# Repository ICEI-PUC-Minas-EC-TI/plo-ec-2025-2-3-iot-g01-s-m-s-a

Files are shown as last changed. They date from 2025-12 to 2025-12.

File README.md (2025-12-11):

# Sistema de Monitoramento de Segurança de um Avião

Pontifícia Universidade Católica de Minas Gerais (PUC Minas) - Campus Lourdes

**Curso:** Engenharia de Computação

**Semestre:** Terceiro

**Disciplina:** Internet das Coisas I

## Integrantes

* Daniel Cássio Ornelas de Almeida
* Flávio Guto Teixeira Bezerra
* Gustavo Parreira Epólita
* Henrique Augusto Figueiredo Feydit Vieira
* Izabela Naves dos Santos

## Orientador

* Julio Cesar Dillinger Conway

## Resumo

Este projeto consiste no desenvolvimento de um protótipo de sistema de monitoramento de segurança interno para aeronaves. O sistema utiliza microcontroladores (ESP32/Arduino) integrados a sensores de pressão, temperatura e peso para detectar despressurização, incêndio e turbulência. Além do monitoramento, o projeto inclui atuadores para portas, luzes e exaustores de emergência, permitindo visualização e controle remoto via aplicativo móvel.

# Código (esp32)

<ol>
<li><a href="Codigo"> Arquivos</a></li>
<li><a href="Codigo/Código Fonte.cpp"> Código Fonte (.cpp)</a></li>
</ol>

# Aplicativo para Smartphone

<ol>
<li><a href="App"> Aplicativo </a></li>
</ol>

# Apresentação

<ol>
<li><a href="Apresentacao/README.md"> Vídeo do Funcionamento</a></li>
<li><a href="Apresentacao/README.md"> Fotos do Projeto</a></li>
</ol>

# Manual de Utilização

<ol>
<li><a href="Manual/manual de utilização.md"> Manual de Utilização</a></li>
</ol>

# Arquivos de modelagem 3D

<ol>
<li><a href="Arquivos 3d"> Arquivos de modelagem 3d</a></li>
</ol>

# Documentação

<ol>
<li><a href="Documentacao/01-Introducão.md"> Introdução</a></li>
<li><a href="Documentacao/02-Metodologias Ágeis.md"> Metodologias Ágeis</a></li>
<li><a href="Documentacao/03-Desenvolvimento.md"> Desenvolvimento </a></li>
<li><a href="Documentacao/04-Testes.md"> Testes </a></li>
<li><a href="Documentacao/05-Conclusão.md"> Conclusão </a></li>
<li><a href="Documentacao/06-Referências.md"> Referências </a></li>
</ol>

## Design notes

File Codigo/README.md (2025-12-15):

# Código-Fonte do Firmware (ESP32)

Este diretório contém o código-fonte C++ desenvolvido para o microcontrolador **ESP32**, responsável por gerenciar todo o sistema de segurança da aeronave. O projeto foi estruturado utilizando o **Visual Studio Code** com a extensão **PlatformIO**.

## Estrutura dos Arquivos

* **`Código Fonte.cpp`**: Arquivo principal contendo a lógica do sistema. Inclui:
    * `setup()`: Inicialização de sensores (I2C), conexão WiFi, configuração de pinos PWM/Servos e WebServer.
    * `loop()`: Gerenciamento de multitarefas (Timers não-bloqueantes), leitura de sensores, filtro complementar (IMU) e comunicação MQTT/WebSocket.
* **`index.html`**: Arquivo de interface (Frontend) hospedado na memória do ESP32 via LittleFS. Contém o código HTML/JavaScript responsável por renderizar o **Horizonte Artificial 3D** e conectar-se ao WebSocket.
* **`platformio.ini`**: Arquivo de configuração do ambiente de desenvolvimento. Define a placa (board), velocidade do monitor serial e as bibliotecas externas necessárias para compilação.

## Dependências e Bibliotecas

Para compilar este projeto, as seguintes bibliotecas são utilizadas (gerenciadas automaticamente pelo `platformio.ini`):

1.  **Sensores:**
    * `MPU6500_WE`: Leitura e calibração do Acelerômetro e Giroscópio.
    * `Adafruit_BMP280`: Leitura de Pressão Atmosférica e Temperatura.
2.  **Conectividade:**
    * `PubSubClient`: Protocolo MQTT para envio de telemetria e recebimento de comandos.
    * `ESPAsyncWebServer` & `AsyncTCP`: Servidor Web assíncrono para hospedar a interface local.
    * `WebSocketsServer`: Comunicação em tempo real para o Horizonte Artificial.
3.  **Atuadores:**
    * `ESP32Servo`: Controle preciso dos servomotores (Portas e Máscaras).

## Principais Funcionalidades Implementadas

### 1. Multitarefa
O código não utiliza `delay()` no loop principal. Foram implementados timers baseados em `millis()` para separar tarefas críticas:
* **100ms (Alta Prioridade):** Leitura do IMU, cálculo de vibração e atualização do WebSocket.
* **1000ms (Baixa Prioridade):** Leitura de Pressão/Temperatura (BMP280) e envio de telemetria pesada via MQTT.

### 2. Filtro Complementar (IMU)
Implementação matemática para fusão de sensores (Acelerômetro + Giroscópio) com fator `ALPHA = 0.96`, eliminando o ruído do acelerômetro e o *drift* do giroscópio para obter ângulos de *Pitch*, *Roll* e *Yaw* estáveis.

### 3. Interface Web (Horizonte Artificial 3D)
O sistema hospeda uma página HTML na memória flash do ESP32 (via sistema de arquivos **LittleFS**).
* **Representação 3D:** A página renderiza um modelo 3D da aeronave que se move em tempo real.
* **Comunicação:** Utiliza **WebSockets** (porta 81) para enviar pacotes JSON contendo os ângulos de Euler calculados pelo filtro. Isso permite que o avião na tela imite instantaneamente os movimentos físicos do protótipo (Digital Twin).

### 4. Modos de Simulação
Sistema de flags que permite simular emergências sem a necessidade de condições físicas reais, ativadas via MQTT ou Serial:
* 🔥 Incêndio (Luzes estroboscópicas + Sirene bitonal).
* 💨 Despressurização (Máscaras caem + Sirene contínua).
* ✈️ Turbulência (Alertas de vibração).

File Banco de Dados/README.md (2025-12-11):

# Apresentação da Solução
## Como rodar o projeto:

### 1. Configuração do Banco
O sistema utiliza o Google Cloud SQL. É necessário criar um banco chamado `IoT` e liberar o IP nas configurações de rede.

### 2. Configuração do Python
Instale as dependências:
pip install paho-mqtt mysql-connector-python

Edite o arquivo `main.py` com suas credenciais do banco e execute:
python main.py

## Código ultilizado:
import paho.mqtt.client as mqtt
import mysql.connector
import sys

# CONFIGURAÇÕES DO GOOGLE CLOUD SQL 
CLOUD_SQL_IP = '34.41.42.27'       
CLOUD_SQL_SENHA = 'SUA_SENHA_AQUI' 

# Configurações do Avião
TOPICO_ALVO = "aviao/sensor/temperaturabmp"
BROKER = "test.mosquitto.org"
PORTA = 1883

print(f"Tentando conectar ao Google Cloud SQL no IP: {CLOUD_SQL_IP}...")

try:
    con = mysql.connector.connect(
        host=CLOUD_SQL_IP,
        user='root',
        password=CLOUD_SQL_SENHA,
        database='IoT' 
    )
except mysql.connector.Error as err:
    print(f"ERRO DE CONEXÃO: {err}")
    print("Dica: Verifique se o IP está correto e se liberou '0.0.0.0/0' nas Redes.")
    sys.exit()

if con.is_connected():
    print(">>> SUCESSO! Conectado ao banco de dados do Google. <<<")
    cursor = con.cursor()

    cursor.execute("""
    CREATE TABLE IF NOT EXISTS dadosIoT (
        id INT AUTO_INCREMENT, 
        mensagem TEXT(512), 
        data_hora TIMESTAMP DEFAULT CURRENT_TIMESTAMP,
        PRIMARY KEY (id)
    );
    """)

def on_connect(client, userdata, flags, rc):
    print(f"Conectado ao Broker MQTT! Assinando: {TOPICO_ALVO}")
    client.subscribe(TOPICO_ALVO)

def on_message(client, userdata, msg):
    mensagem = str(msg.payload.decode())
    print(f"Recebido do Avião: {mensagem}°C")

    try:
        # Reconecta o cursor para garantir
        cursor = con.cursor()
        sql = "INSERT INTO dadosIoT (mensagem) VALUES (%s)"
        cursor.execute(sql, (mensagem,))
        con.commit()
        print(">> Enviado para a nuvem Google Cloud!")
    except mysql.connector.Error as err:
        print(f"Erro ao salvar na nuvem: {err}")

if __name__ == '__main__':
    client = mqtt.Client()
    client.on_connect = on_connect
    client.on_message = on_message
    client.connect(BROKER, PORTA, 60)
    client.loop_forever()

## Imagens do funcionamento do banco de dados:
funcionamento 4
funcionamento 3
funcionamento 2
funcionamento 1

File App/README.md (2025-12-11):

# Interface de Monitoramento Móvel (Dashboard)

Este diretório contém os arquivos de configuração para a interface móvel do projeto. Utilizamos um aplicativo MQTT para criar um **Dashboard** que permite visualizar a telemetria do avião em tempo real e enviar comandos de simulação.

## Aplicativo Utilizado

Para utilizar a interface, é necessário instalar o seguinte aplicativo para smartphone (Android):

* **Nome:** MQTT Dashboard Client
* **Desenvolvedor:** Doikov Evgenii
* **Link:** [Disponível na Google Play Store](https://play.google.com/store/apps/details?id=com.doikov.mqttclient)

## Arquivos Neste Diretório

* **`MqttDashboardClient_Backup`** : Este arquivo contém o layout completo e pré-configurado de todos os painéis, botões e gráficos mostrados nas demonstrações do projeto.

## Funcionalidades do Painel

Ao importar o arquivo de configuração, você terá acesso imediato às seguintes abas e controles:

### 1. Cabine e Ambiente
* **Telemetria:** Temperatura Interna (MPU), Temperatura Externa (BMP) e Pressão Atmosférica.
* **Controle Manual de Atuadores:** Botões interativos para acionamento direto:
    * **Portas:** Switch para Abrir/Fechar a porta manualmente.
    * **Máscaras:** Switch para Liberar/Recolher as máscaras de oxigênio.

### 2. Alertas de Segurança
* **Indicadores de Emergência:** Luzes de alerta que se ativam automaticamente em caso de:
    * 🔥 Incêndio
    * 💨 Despressurização
    * ✈️ Turbulência

### 3. Sensores Inerciais (IMU)
* **Acelerômetro e Giroscópio:** Leitura em tempo real dos eixos X, Y e Z para monitoramento da estabilidade da aeronave.

### 4. Controle de Simulação
* **Botões de Teste:** Switches para ativar/desativar manualmente os modos de emergência (Incêndio, Despressurização, Turbulência) para fins de apresentação e testes de bancada.

### 5. Conectividade
* **WiFi IP:** Exibe o endereço IP atual do ESP32 para facilitar o acesso à página Web do Horizonte Artificial.

---

## Como Importar o Painel

1.  Baixe o arquivo de configuração disponível nesta pasta para o seu celular.
2.  Extraia o arquivo compactado, para obter o arquivo original.
3.  Abra o aplicativo **MQTT Dashboard**.
4.  Vá no menu de configurações e selecione **"Restore / Import"** (ou similar).
5.  Selecione o arquivo baixado.
6.  O painel carregará automaticamente com todos os tópicos MQTT já configurados.

> **Nota:** Certifique-se de configurar o *Broker* (endereço do servidor MQTT) no aplicativo caso ele não seja importado automaticamente com o arquivo.

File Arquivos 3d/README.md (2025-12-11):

# Modelagem e Impressão 3D

Este diretório contém todos os arquivos necessários para a fabricação das peças estruturais, suportes de sensores e cases do projeto.

## Softwares Utilizados

As peças foram desenvolvidas e preparadas utilizando as seguintes ferramentas:

* **[Autodesk Fusion 360](https://www.autodesk.com/products/fusion-360/overview):** Utilizado para a modelagem paramétrica e design das peças (`.f3d`).
* **[Orca Slicer](https://github.com/SoftFever/OrcaSlicer):** Utilizado para o fatiamento e geração do G-Code para a impressora.

## Estrutura dos Arquivos

* **`/STL`**: Arquivos de malha prontos para serem importados no fatiador.
* **`/Fusion360`** (ou `.f3d`): Arquivos editáveis originais do projeto.
* **`/Gcode`** (Opcional): Arquivos já fatiados para a impressora específica do projeto.

## Lista de Peças

Abaixo estão os arquivos de malha prontos para impressão disponíveis nesta pasta:

### Estrutura Principal
* **`Fuselagem.stl`**: Corpo principal da aeronave, projetado para servir de base e acomodar a eletrônica central.
* **`Bico.stl`**: Parte frontal (nariz) do avião, onde também está localizada a porta. Esconde partes da eletrônica, como buzzer e pilhas.
* **`Conexão.stl`**: Elemento estrutural para junção das partes do corpo, incluindo locais para fixação da válvula para pressurizar e botão para ligar e desligar.

### Interior e Suportes
* **`Piso parte 1.stl`** e **`Piso parte2.stl`**: Base interna plana para fixação segura do ESP32, placa de desenvolvimento e sensores.
* **`tampao.stl`**: Peça de fechamento/acabamento para a parte traseira do avião.

### Mecanismos Móveis
* **`Porta.stl`**: Componente móvel acionado pelo servo motor (simulação de porta de emergência).

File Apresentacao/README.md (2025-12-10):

# Apresentação da Solução
* Vídeo com o funcionamento do sensor de pressão: https://github.com/user-attachments/assets/d2db7d52-17c9-47eb-adb4-de0ecd05f36d
* 

# # Trabalho interdiciplinar: 

* **Local:** Escola Municipal Professora Helena Abdala
* **Atividade:** Demonstração do Projeto e Oficina de Introdução à Robótica

## 1. O Objetivo
Como parte do nosso projeto de Internet das Coisas, realizamos uma visita à Escola Municipal Professora Helena Abdala. O objetivo foi democratizar o conhecimento técnico, apresentando aos alunos como a engenharia pode resolver problemas reais e introduzindo conceitos básicos de eletrônica e programação.

## 2. Demonstração do Projeto
Apresentamos aos alunos o nosso Sistema de Monitoramento de Segurança de Avião. Explicamos como a tecnologia IoT é aplicada na aviação para garantir a segurança dos passageiros.

Demonstramos o funcionamento prático dos componentes do nosso protótipo:
**Sensores:** Mostramos como o sistema detecta mudanças críticas, como despressurização e temperatura
**Atuadores:** Exibimos a atuação automática das portas e luzes de emergência em situações de perigo simuladas
**Visualização:** Explicamos como esses dados são enviados para o celular para monitoramento remoto

## 3. Prática com Tinkercad
Para engajar os alunos na prática, realizamos um workshop utilizando a plataforma **Tinkercad**.
* **Atividade:** "Como ligar um LED".
* **Dinâmica:** Guiamos os alunos na montagem de um circuito virtual básico, explicando conceitos de corrente elétrica, protoboard e programação simples.
* [Sistema de segurança de um avião.pdf](https://github.com/user-attachments/files/24089589/Sistema.de.seguranca.de.um.aviao.pdf)

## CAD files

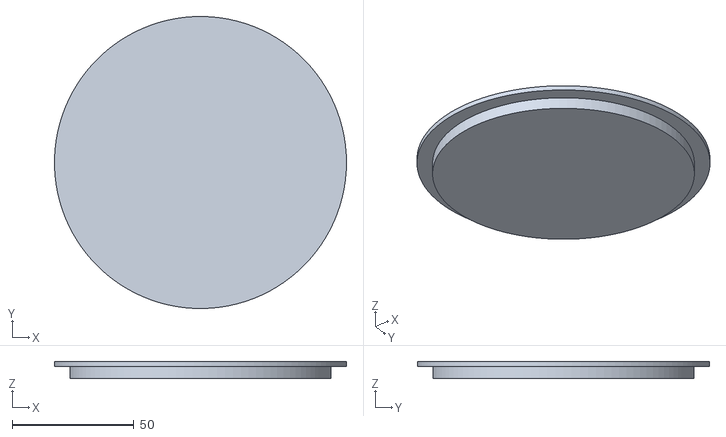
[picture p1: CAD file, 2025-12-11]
Arquivos 3d/tampao.stl
120.0 x 120.0 x 7.00

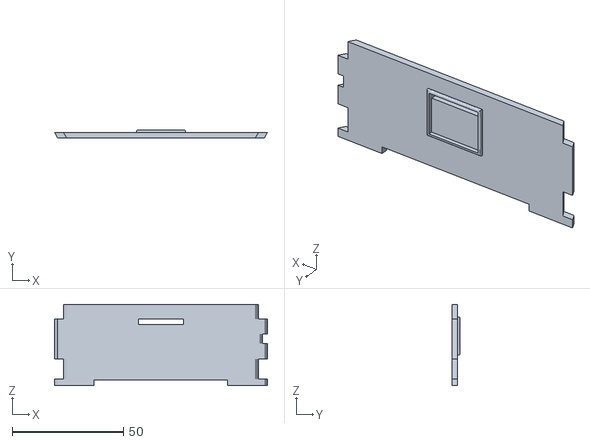
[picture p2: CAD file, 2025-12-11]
Arquivos 3d/Piso parte2.stl
95.6 x 3.50 x 36.6

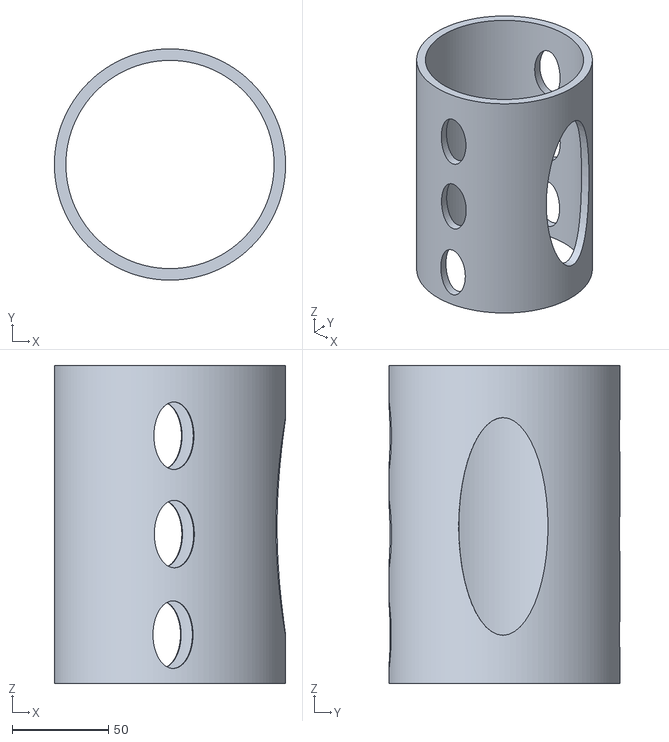
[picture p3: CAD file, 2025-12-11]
Arquivos 3d/Fuselagem.stl
120.0 x 120.0 x 165.0

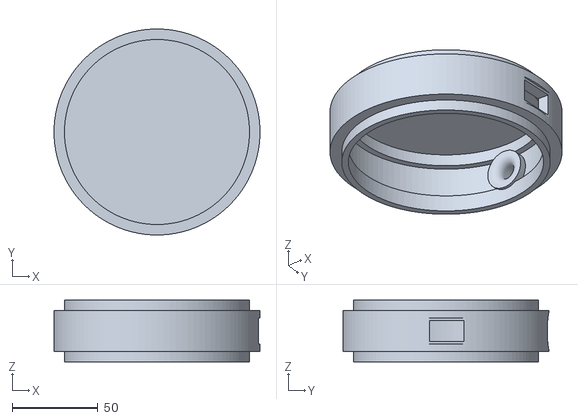
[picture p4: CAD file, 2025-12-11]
Arquivos 3d/Conexão.stl
120.0 x 120.0 x 36.0

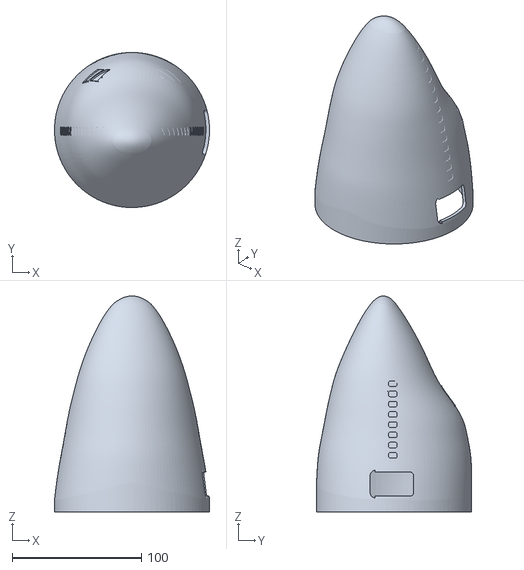
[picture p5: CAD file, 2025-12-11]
Arquivos 3d/Bico.stl
120.0 x 120.0 x 167.2

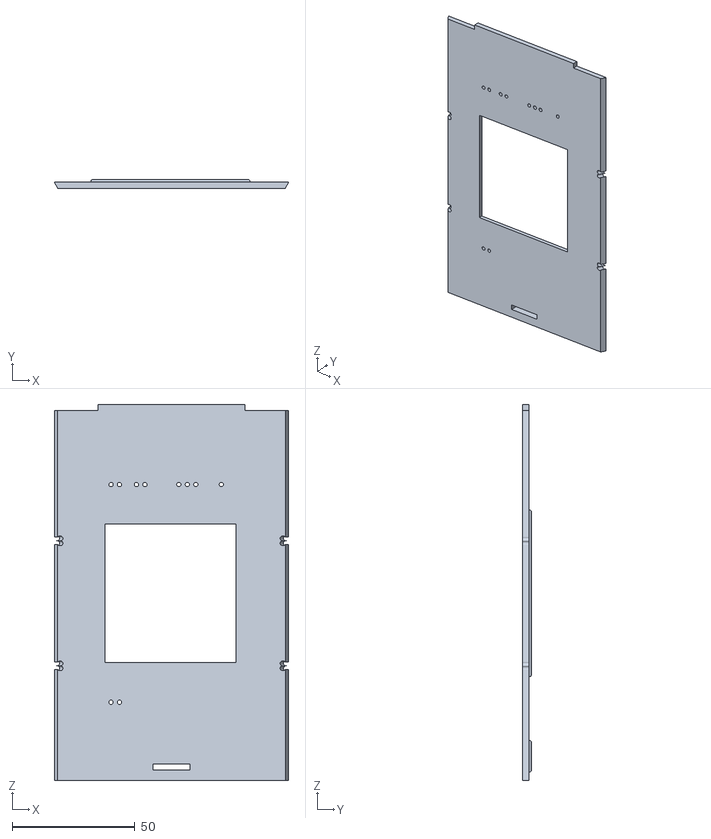
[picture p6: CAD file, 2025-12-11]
Arquivos 3d/Piso parte 1.stl
95.6 x 3.50 x 153.4

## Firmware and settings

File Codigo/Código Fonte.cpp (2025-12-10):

#include <Arduino.h>
#include <WiFi.h>
#include <AsyncTCP.h>
#include <ESPAsyncWebServer.h>
#include <WebSocketsServer.h>
#include <Wire.h>
#include <MPU6500_WE.h>
#include <Adafruit_BMP280.h>
#include "LittleFS.h"
#include <PubSubClient.h>
#include <ESP32Servo.h>

// CONFIGURAÇÕES DE HARDWARE E REDE
// Endereços I2C
#define MPU6500_ADDR 0x68
#define BMP280_ADDR  0x76

// Credenciais WiFi e MQTT
const char* ssid = "S23 de Flávio";       // SUBSTITUA SE NECESSÁRIO
const char* password = "senha1313";       // SUBSTITUA SE NECESSÁRIO

const char* BROKER_MQTT = "test.mosquitto.org";
const int BROKER_PORT = 1883;
const char* ID_MQTT = "esp32_aviao_seguranca_final";

// Definição dos Pinos
const int PIN_LED_LUZES = 2;      // LED de Alerta Visual
const int PIN_BUZZER = 4;         // Sirene 
const int PIN_PORTA_SERVO = 18;   // Servo 1 (Portas)
const int PIN_MASCARA_SERVO = 19; // Servo 2 (Máscaras)
const int CANAL_PWM_BUZZER = 12;  // Canal para controlar PWM buzzer

// Limiares de Sensores (Ajuste Fino)
const float LIMITE_PRESSAO_MINIMA = 900.0;  // hPa
const float LIMITE_TEMPERATURA_FOGO = 40.0; // °C
const float LIMITE_VIBRACAO = 0.5;          // G

// TÓPICOS MQTT
// Publicação
#define TOPICO_STATUS "aviao/sensor/status" 
#define TOPICO_PRESSAO "aviao/sensor/pressao"
#define TOPICO_TEMPERATURA_BMP "aviao/sensor/temperaturabmp"
#define TOPICO_TEMPERATURA_MPU "aviao/sensor/temperaturampu"
#define TOPICO_TURBULENCIA "aviao/sensor/turbulencia"
#define TOPICO_INCENDIO "aviao/sensor/incendio"

#define TOPICO_ACC_X "aviao/sensor/accx"
#define TOPICO_ACC_Y "aviao/sensor/accy"
#define TOPICO_ACC_Z "aviao/sensor/accz"
#define TOPICO_GYR_X "aviao/sensor/gyrx"
#define TOPICO_GYR_Y "aviao/sensor/gyry"
#define TOPICO_GYR_Z "aviao/sensor/gyrz"

#define TOPICO_ALERTA_INCENDIO "aviao/alerta/incendio"
#define TOPICO_ALERTA_DESPRESSURIZACAO "aviao/alerta/despressurizacao"
#define TOPICO_ALERTA_TURBULENCIA "aviao/alerta/turbulencia"

// Inscrição (Comandos)
#define TOPICO_SUBSCRIBE_LUZES  "aviao/atuador/luzes"
#define TOPICO_SUBSCRIBE_SIRENE "aviao/atuador/sirene"
#define TOPICO_SUBSCRIBE_PORTAS "aviao/atuador/portas"
#define TOPICO_SUBSCRIBE_MASCARAS "aviao/atuador/mascaras"
#define TOPICO_SUBSCRIBE_SIMULACAO_INCENDIO "aviao/simulacao/incendio"
#define TOPICO_SUBSCRIBE_SIMULACAO_DESPRESSURIZACAO "aviao/simulacao/despressurizacao"
#define TOPICO_SUBSCRIBE_SIMULACAO_TURBULENCIA "aviao/simulacao/turbulencia"

#define TOPICO_INFO_IP "aviao/info/ip"

// VARIÁVEIS GLOBAIS
Servo cleber;   // Servo Portas
Servo pryscila; // Servo Máscaras

MPU6500_WE mpu = MPU6500_WE(MPU6500_ADDR);
Adafruit_BMP280 bmp;

AsyncWebServer server(80);
WebSocketsServer webSocket = WebSocketsServer(81);

WiFiClient espClient;
PubSubClient MQTT(espClient);

// VARIÁVEIS DO FILTRO
float anguloPitch = 0;
float anguloRoll = 0;
float anguloYaw = 0;
unsigned long lastTimeFilter = 0;
const float ALPHA = 0.96; 

int ledFase = 0; 
int sireneFase = 0;
int modoLedGlobal = 0;
int modoSireneGlobal = 0;
unsigned long ledTimer = 0;
unsigned long sireneTimer = 0;
bool estadoSirene = false;

bool lastStateIncendio = false;
bool lastStateDespressurizacao = false;
bool lastStateTurbulencia = false;

unsigned long timerRUIDO = 0;      
const unsigned long INTERVALO_RUIDO = 100; // 10Hz (Mantém animação fluida)

// Timer 2: Lento (Clima/Pressão/MQTT pesado)
unsigned long timerCLIMA = 0;      
const unsigned long INTERVALO_CLIMA = 1000; // 1Hz (Lê BMP a cada 1 segundo)

// Variáveis Globais para armazenar o último valor lido
float globalPressao = 1013.25;
float globalTempBMP = 25.0;
float globalVibracao = 0.0;

const unsigned long INTERVALO_LEITURA = 150; //(ajuste se precisar)

unsigned long ultimoTempoTurbulencia = 0; 
const unsigned long TEMPO_ESPERA_TURBULENCIA = 3000; // 5000ms = 5 segundos
unsigned long ultimoTempoDespressurizacao = 0;
const unsigned long TEMPO_ESPERA_DESPRESSURIZACAO = 3000; // 5000ms = 5 segundos
unsigned long ultimoTempoIcendio = 0;
const unsigned long TEMPO_ESPERA_INCENDIO = 3000; // 5000ms = 5 segundos

// Flags de Simulação (Serial)
bool simDespressurizacao = false;
bool simIncendio = false;
bool simTurbulencia = false;
bool manualPortaAberta = false;    // Guarda se a porta foi aberta via App
bool manualMascarasSoltas = false; // Guarda se as máscaras foram soltas via App

char msgBuffer[50];  
char jsonBuffer[256];

// Protótipo das Funções
void initMQTT();
void reconnectMQTT();
void mqtt_callback(char* topic, byte* payload, unsigned int length);
void VerificaConexoesWiFIEMQTT();
void monitoraSensores();
void gerenciarLeds(int modo);
void gerenciarSirene(int modo);
void verificarComandosSerial();
void atualizarFiltroIMU();
void conectarWiFiComEfeitos();

// SETUP
void setup() {
  Serial.begin(115200);
  Wire.begin();
  Wire.setClock(400000);
  
  // Configuração dos Servos
  cleber.setPeriodHertz(50);
  cleber.attach(PIN_PORTA_SERVO, 500, 2400);
  pryscila.setPeriodHertz(50);
  pryscila.attach(PIN_MASCARA_SERVO, 500, 2400);

  // Posição Inicial
  cleber.write(0);
  pryscila.write(50);

  // Configuração dos Pinos (LEDs e Buzzer)
  pinMode(PIN_LED_LUZES, OUTPUT);
  digitalWrite(PIN_LED_LUZES, LOW);
  // digitalWrite(PIN_BUZZER, LOW); // Comentado pois vamos usar PWM

  ledcSetup(CANAL_PWM_BUZZER, 2000, 8); // Configura canal de som
  ledcAttachPin(PIN_BUZZER, CANAL_PWM_BUZZER); // Liga o pino ao canal

  // Inicialização de Rede e Arquivos
  initMQTT();
  if (!LittleFS.begin()) {
    Serial.println("Aviso: Falha ao montar LittleFS");
  }

  conectarWiFiComEfeitos();

  // Inicialização de Sensores
  if (!bmp.begin(BMP280_ADDR)) {
    Serial.println("ERRO: BMP280 não encontrado!");
  } else {
    Serial.println("BMP280 OK");
  }

  if (!mpu.init()) {
    Serial.println("ERRO: MPU6500 não encontrado!");
  } else {
    Serial.println("MPU6500 OK");
    Serial.println("Calibrando... não mexa!");
    delay(1000);
    mpu.autoOffsets(); 
    Serial.println("Calibrado.");
  }
  
  // Servidor Web e WebSocket
  server.on("/", HTTP_GET, [](AsyncWebServerRequest *request){
    request->send(LittleFS, "/index.html", "text/html");
  });
  server.serveStatic("/", LittleFS, "/");
  server.begin();
  webSocket.begin();
  
  // Instruções no Serial
  Serial.println("\n--- SISTEMA PRONTO ---");
  Serial.println("Use o Monitor Serial para testes manuais:");
  Serial.println("- Digite '1' para simular despressurização");
  Serial.println("- Digite '2' para simular incêndio");
  Serial.println("- Digite '3' para simular turbulência");
  Serial.println("- Digite '4' para voltar ao normal");
  Serial.println("------------------------");
  
  lastTimeFilter = millis(); 
}

// LOOP PRINCIPAL
void loop() {
  VerificaConexoesWiFIEMQTT();
  MQTT.loop(); 
  webSocket.loop();
  verificarComandosSerial();
  
  // O filtro roda livre para garantir precisão nos ângulos
  atualizarFiltroIMU();

  unsigned long atual = millis();
  
  if (atual - timerRUIDO >= INTERVALO_RUIDO) {
    timerRUIDO = atual; 

    // LER DADOS BRUTOS (Faltava ler o Giroscópio aqui)
    xyzFloat acc = mpu.getGValues();
    xyzFloat gyr = mpu.getGyrValues(); // <--- ADICIONADO
    
    // CÁLCULO DE VIBRAÇÃO
    float gTotal = sqrt(acc.x * acc.x + acc.y * acc.y + acc.z * acc.z);
    globalVibracao = abs(gTotal - 1.0); 

    // MONITORAMENTO DE ALARMES
    monitoraSensores();

    // WEBSOCKET (Envia ÂNGULOS para o Horizonte Artificial)
    // Nota: O App espera "gyroX" mas enviamos o anguloRoll (radianos) para o desenho se mexer
    float toRad = 0.0174533;
    snprintf(jsonBuffer, sizeof(jsonBuffer), 
        "{\"gyroX\":%.4f,\"gyroY\":%.4f,\"gyroZ\":%.4f,\"tempBMP\":%.2f,\"pressao\":%.2f}",
        anguloRoll * toRad, 
        anguloPitch * toRad, 
        anguloYaw * toRad, 
        globalTempBMP, 
        globalPressao 
    );
    webSocket.broadcastTXT(jsonBuffer);
    
    //MQTT DADOS RÁPIDOS
    if(MQTT.connected()) {
         // Acelerômetro
         snprintf(msgBuffer, sizeof(msgBuffer), "%.2f", acc.x); MQTT.publish(TOPICO_ACC_X, msgBuffer);
         snprintf(msgBuffer, sizeof(msgBuffer), "%.2f", acc.y); MQTT.publish(TOPICO_ACC_Y, msgBuffer);
         snprintf(msgBuffer, sizeof(msgBuffer), "%.2f", acc.z); MQTT.publish(TOPICO_ACC_Z, msgBuffer);
         
         // Giroscópio (Adicionado agora)
         snprintf(msgBuffer, sizeof(msgBuffer), "%.2f", gyr.x); MQTT.publish(TOPICO_GYR_X, msgBuffer);
         snprintf(msgBuffer, sizeof(msgBuffer), "%.2f", gyr.y); MQTT.publish(TOPICO_GYR_Y, msgBuffer);
         snprintf(msgBuffer, sizeof(msgBuffer), "%.2f", gyr.z); MQTT.publish(TOPICO_GYR_Z, msgBuffer);
    }
  }

  if (atual - timerCLIMA >= INTERVALO_CLIMA) {
    timerCLIMA = atual;

    // Lê Sensores Lentos
    globalTempBMP = bmp.readTemperature();
    globalPressao = bmp.readPressure() / 100.0; 
    float tempMPU = mpu.getTemperature();

    // Envia MQTT Lento
    if(MQTT.connected()) {
        snprintf(msgBuffer, sizeof(msgBuffer), "%.2f", globalTempBMP); MQTT.publish(TOPICO_TEMPERATURA_BMP, msgBuffer);
        snprintf(msgBuffer, sizeof(msgBuffer), "%.2f", globalPressao); MQTT.publish(TOPICO_PRESSAO, msgBuffer);
        snprintf(msgBuffer, sizeof(msgBuffer), "%.2f", tempMPU); MQTT.publish(TOPICO_TEMPERATURA_MPU, msgBuffer);
    }
  }

  gerenciarLeds(modoLedGlobal);
  gerenciarSirene(modoSireneGlobal);
}

// IMPLEMENTAÇÃO DO FILTRO 
void atualizarFiltroIMU() {
  // Controle de tempo delta (dt)
  unsigned long tAtual = millis();
  float dt = (tAtual - lastTimeFilter) / 1000.0;
  lastTimeFilter = tAtual;

  // Lê dados brutos
  xyzFloat acc = mpu.getGValues();     
  xyzFloat gyr = mpu.getGyrValues();   

  // --- CORREÇÃO DO GIRO "FANTASMA" (DEADZONE) ---
  // Se a rotação for menor que 0.2 graus/s, consideramos como 0 (ruído)
  // Aumente para 0.5 ou 1.0 se continuar girando sozinho.
  if (abs(gyr.x) < 0.2) gyr.x = 0;
  if (abs(gyr.y) < 0.2) gyr.y = 0;
  if (abs(gyr.z) < 0.2) gyr.z = 0;

  // Calcula inclinação baseada APENAS na gravidade (Acelerômetro)
  float accPitch = atan2(acc.y, sqrt(acc.x * acc.x + acc.z * acc.z)) * 57.296;
  float accRoll  = atan2(-acc.x, sqrt(acc.y * acc.y + acc.z * acc.z)) * 57.296;

  // Filtro Complementar
  anguloPitch = ALPHA * (anguloPitch + gyr.y * dt) + (1.0 - ALPHA) * accPitch;
  anguloRoll  = ALPHA * (anguloRoll  + gyr.x * dt) + (1.0 - ALPHA) * accRoll;
  
  // Yaw (Esse é o que mais gira sozinho, pois não tem acelerômetro para corrigir)
  anguloYaw   = anguloYaw + gyr.z * dt;
}

// Leitura do Serial para ativar flags de simulação
void verificarComandosSerial() {
    if (Serial.available() > 0) {
        String comando = Serial.readStringUntil('\n');
        comando.trim(); 
        comando.toUpperCase(); 

        if (comando == "1") {
            simDespressurizacao = !simDespressurizacao;
            Serial.print("SIMULAÇÃO PRESSÃO: ");
            Serial.println(simDespressurizacao ? "ATIVADA" : "DESATIVADA");
        }
        else if (comando == "2") {
            simIncendio = !simIncendio;
            Serial.print("SIMULAÇÃO FOGO: ");
            Serial.println(simIncendio ? "ATIVADA" : "DESATIVADA");
        }
        else if (comando == "3") {
            simTurbulencia = !simTurbulencia;
            Serial.print("SIMULAÇÃO TURBULÊNCIA: ");
            Serial.println(simTurbulencia ? "ATIVADA" : "DESATIVADA");
        }
        else if (comando == "4") {
            simDespressurizacao = false;
            simIncendio = false;
            simTurbulencia = false;
            Serial.println("TODAS AS SIMULAÇÕES PARADAS. Lendo sensores reais.");
        }
    }
}

void monitoraSensores() {
    // 1. Atualiza Flags de Tempo baseadas nos sensores ou simulação
    if ((globalVibracao > LIMITE_VIBRACAO) || simTurbulencia) ultimoTempoTurbulencia = millis(); 
    if ((globalPressao < LIMITE_PRESSAO_MINIMA) || simDespressurizacao) ultimoTempoDespressurizacao = millis();
    if ((globalTempBMP > LIMITE_TEMPERATURA_FOGO) || simIncendio) ultimoTempoIcendio = millis();

    // 2. Determina o estado ATUAL (True/False)
    bool isTurbulencia = (millis() - ultimoTempoTurbulencia < TEMPO_ESPERA_TURBULENCIA);
    bool isDespressurizacao = (millis() - ultimoTempoDespressurizacao < TEMPO_ESPERA_DESPRESSURIZACAO);
    bool isIncendio = (millis() - ultimoTempoIcendio < TEMPO_ESPERA_INCENDIO);

    // 3. Controla Servos (Atuadores Físicos)
    if (manualPortaAberta) cleber.write(90); else cleber.write(0);                   
    if (isDespressurizacao || manualMascarasSoltas) pryscila.write(180); else pryscila.write(50);                      

    // 4. Lógica de Prioridade para LEDs e Sirene
    if (isIncendio) {
        modoLedGlobal = 3; modoSireneGlobal = 3; 
    }
    else if (isDespressurizacao) {
        modoLedGlobal = 1; modoSireneGlobal = 1; 
    }
    else if (isTurbulencia) {
        modoLedGlobal = 2; modoSireneGlobal = 2; 
    }
    else {
        modoLedGlobal = 0; modoSireneGlobal = 0;
    }
    
    // --- Check Incêndio ---
    if (isIncendio != lastStateIncendio) {
        lastStateIncendio = isIncendio; // Atualiza memória
        MQTT.publish(TOPICO_ALERTA_INCENDIO, isIncendio ? "true" : "false");
        Serial.print("Mudança Estado Incêndio: "); Serial.println(isIncendio);
    }

    // --- Check Despressurização ---
    if (isDespressurizacao != lastStateDespressurizacao) {
        lastStateDespressurizacao = isDespressurizacao;
        MQTT.publish(TOPICO_ALERTA_DESPRESSURIZACAO, isDespressurizacao ? "true" : "false");
         Serial.print("Mudança Estado Despress: "); Serial.println(isDespressurizacao);
    }

    // --- Check Turbulência ---
    if (isTurbulencia != lastStateTurbulencia) {
        lastStateTurbulencia = isTurbulencia;
        MQTT.publish(TOPICO_ALERTA_TURBULENCIA, isTurbulencia ? "true" : "false");
         Serial.print("Mudança Estado Turbulencia: "); Serial.println(isTurbulencia);
    }
}

// Gerenciador de Padrão de LED
void gerenciarLeds(int modo) {
    // MODO 0: Tudo Apagado
    if (modo == 0) {
        digitalWrite(PIN_LED_LUZES, LOW);
        ledFase = 0; 
        return;
    }

    unsigned long atual = millis();

    // MODO 1: EMERGÊNCIA CRÍTICA
    if (modo == 1) {
        switch (ledFase) {
            case 0: 
                digitalWrite(PIN_LED_LUZES, HIGH);
                if (atual - ledTimer >= 2000) { ledTimer = atual; ledFase = 1; }
                break;
            case 1: 
                digitalWrite(PIN_LED_LUZES, LOW);
                if (atual - ledTimer >= 250) { ledTimer = atual; ledFase = 2; }
                break;
            case 2: 
                digitalWrite(PIN_LED_LUZES, HIGH);
                if (atual - ledTimer >= 500) { ledTimer = atual; ledFase = 3; }
                break;
            case 3: 
                digitalWrite(PIN_LED_LUZES, LOW);
                if (atual - ledTimer >= 250) { ledTimer = atual; ledFase = 0; } 
                break;
            default: ledFase = 0; break;
        }
    }
    
    // MODO 2: TURBULÊNCIA
    else if (modo == 2) {
        switch (ledFase) {
            case 0: 
                digitalWrite(PIN_LED_LUZES, HIGH);
                if (atual - ledTimer >= 200) { ledTimer = atual; ledFase = 1; }
                break;
            case 1: 
                digitalWrite(PIN_LED_LUZES, LOW);
                if (atual - ledTimer >= 200) { ledTimer = atual; ledFase = 2; }
                break;
            case 2: 
                digitalWrite(PIN_LED_LUZES, HIGH);
                if (atual - ledTimer >= 200) { ledTimer = atual; ledFase = 3; }
                break;
            case 3: 
                digitalWrite(PIN_LED_LUZES, LOW);
                if (atual - ledTimer >= 1000) { ledTimer = atual; ledFase = 0; } 
                break;
            default: ledFase = 0; break; 
        }
    }
    // MODO 
    else if (modo == 3) {
        switch (ledFase) {
            case 0: // Flash 1
                digitalWrite(PIN_LED_LUZES, HIGH);
                if (atual - ledTimer >= 50) { ledTimer = atual; ledFase = 1; }
                break;
            case 1: // Intervalo
                digitalWrite(PIN_LED_LUZES, LOW);
                if (atual - ledTimer >= 50) { ledTimer = atual; ledFase = 2; }
                break;
            case 2: // Flash 2
                digitalWrite(PIN_LED_LUZES, HIGH);
                if (atual - ledTimer >= 50) { ledTimer = atual; ledFase = 3; }
                break;
            case 3: // Intervalo
                digitalWrite(PIN_LED_LUZES, LOW);
                if (atual - ledTimer >= 50) { ledTimer = atual; ledFase = 4; }
                break;
            case 4: // Flash 3
                digitalWrite(PIN_LED_LUZES, HIGH);
                if (atual - ledTimer >= 50) { ledTimer = atual; ledFase = 5; }
                break;
            case 5: // Pausa Longa
                digitalWrite(PIN_LED_LUZES, LOW);
                if (atual - ledTimer >= 800) { ledTimer = atual; ledFase = 0; } // Reinicia
                break;
            default: ledFase = 0; break; 
        }
    }
}

// Gerenciador de Sirene (USANDO LEDC/PWM para não travar Servo)
void gerenciarSirene(int modo) {
    if (modo == 0) {
        ledcWrite(CANAL_PWM_BUZZER, 0); // Mudo
        estadoSirene = false;
        sireneFase = 0;
        return;
    }

    unsigned long atual = millis();
    unsigned long intervalo;
    int frequencia;

    //Despressurizacao
    if(modo == 1) {
      intervalo = 100;
      frequencia = 2000;
      if (atual - sireneTimer >= intervalo) {
            sireneTimer = atual;
            estadoSirene = !estadoSirene; 
            if (estadoSirene) {
                ledcSetup(CANAL_PWM_BUZZER, frequencia, 8);
                ledcWrite(CANAL_PWM_BUZZER, 128); // Volume médio
            } else {
                ledcWrite(CANAL_PWM_BUZZER, 0); // Silêncio
            }
        }
    }

    // Turbulencia
    else if(modo == 2) {
      intervalo = 500;
      frequencia = 1000;
      if (atual - sireneTimer >= intervalo) {
            sireneTimer = atual;
            estadoSirene = !estadoSirene; 
            if (estadoSirene) {
                ledcSetup(CANAL_PWM_BUZZER, frequencia, 8);
                ledcWrite(CANAL_PWM_BUZZER, 128); // Volume médio
            } else {
                ledcWrite(CANAL_PWM_BUZZER, 0); // Silêncio
            }
        }
    }

    // Incendio 
    else if (modo == 3) { 
        if (atual - sireneTimer >= 400) { 
            sireneTimer = atual; 
            estadoSirene = !estadoSirene; 
            ledcSetup(CANAL_PWM_BUZZER, estadoSirene ? 1200 : 800, 8); 
            ledcWrite(CANAL_PWM_BUZZER, 128);
        }
    }
}

// FUNÇÕES DE REDE (MQTT)
void initMQTT() {
    MQTT.setServer(BROKER_MQTT, BROKER_PORT);
    MQTT.setCallback(mqtt_callback);
}

void reconnectMQTT() {
    while (!MQTT.connected()) {
        // --- SEGURANÇA: ESCAPE SE O WIFI CAIR ---
        if(WiFi.status() != WL_CONNECTED) {
          Serial.println("WiFi caiu durante tentativa MQTT. Abortando...");
          return; 
        }

        Serial.print("* Tentando MQTT... ");
        
        // Tenta conectar
        if (MQTT.connect(ID_MQTT)) {
            Serial.println("Conectado!");
            
            // --- CORREÇÃO: O ENVIO DO IP TEM QUE SER AQUI (DEPOIS DE CONECTAR) ---
            MQTT.publish(TOPICO_INFO_IP, WiFi.localIP().toString().c_str());
            Serial.print("IP enviado para o topico: ");
            Serial.println(WiFi.localIP());
            // ---------------------------------------------------------------------

            MQTT.publish(TOPICO_STATUS, "ESP32 Online");
            
            // Reinscreve nos tópicos
            MQTT.subscribe(TOPICO_SUBSCRIBE_LUZES);
            MQTT.subscribe(TOPICO_SUBSCRIBE_SIRENE);
            MQTT.subscribe(TOPICO_SUBSCRIBE_PORTAS);
            MQTT.subscribe(TOPICO_SUBSCRIBE_MASCARAS);
            MQTT.subscribe(TOPICO_SUBSCRIBE_SIMULACAO_INCENDIO);
            MQTT.subscribe(TOPICO_SUBSCRIBE_SIMULACAO_DESPRESSURIZACAO);
            MQTT.subscribe(TOPICO_SUBSCRIBE_SIMULACAO_TURBULENCIA);
            
        } else {
            Serial.print("Falha rc=");
            Serial.print(MQTT.state());
            Serial.println(" tentando em 2s");
            delay(2000);
        }
    }
}

void VerificaConexoesWiFIEMQTT() {
    // PRIMEIRO: Verifica se o WiFi caiu
    if (WiFi.status() != WL_CONNECTED) {
        Serial.println("Detectado queda de WiFi!");
        conectarWiFiComEfeitos(); // Entra no loop de bips e luzes até voltar
        return; // Sai da função para não tentar MQTT sem internet
    }

    // DEPOIS: Se WiFi está OK, verifica MQTT
    if (!MQTT.connected()) {
        reconnectMQTT();
    }
}
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

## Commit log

2025-12-10 Add video link for pressure sensor demonstration
    Added a link to the video demonstrating the pressure sensor functionality.
2025-12-10 Add files via upload
    Arquivo de configuração principal do PlatformIO que define a placa, o framework, as bibliotecas e os parâmetros de compilação.
2025-12-11 Arquivo de restauração MQTT Dashboard Client
2025-12-15 Atualização da pagina web
    Adicionado botão para redefinir a posição do modelo 3d do avião
